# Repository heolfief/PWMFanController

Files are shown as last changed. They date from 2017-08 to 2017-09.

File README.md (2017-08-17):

# PWMFanController
This is a simple AVR based PWM PC fan controller.

The MCU is an ATtiny85.

Software in interrupt-driven. A potentiometer value is read by the ADC and then used to set the duty-cycle of a 8bits PWM, driving the fan's speed.

The board is small (33x15mm) and is designed to be directly attached to a standard potentiometer.

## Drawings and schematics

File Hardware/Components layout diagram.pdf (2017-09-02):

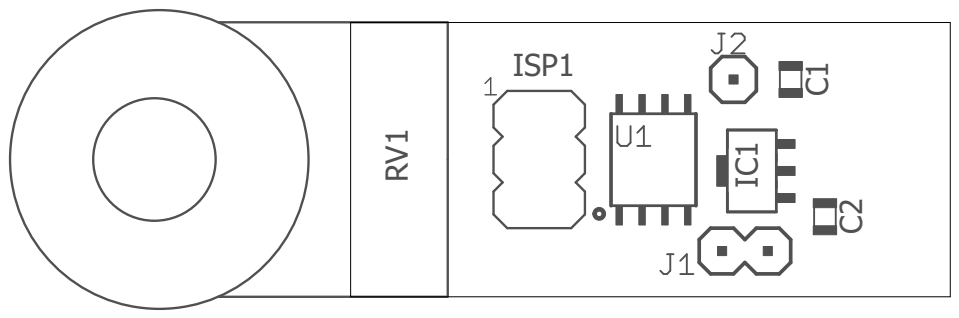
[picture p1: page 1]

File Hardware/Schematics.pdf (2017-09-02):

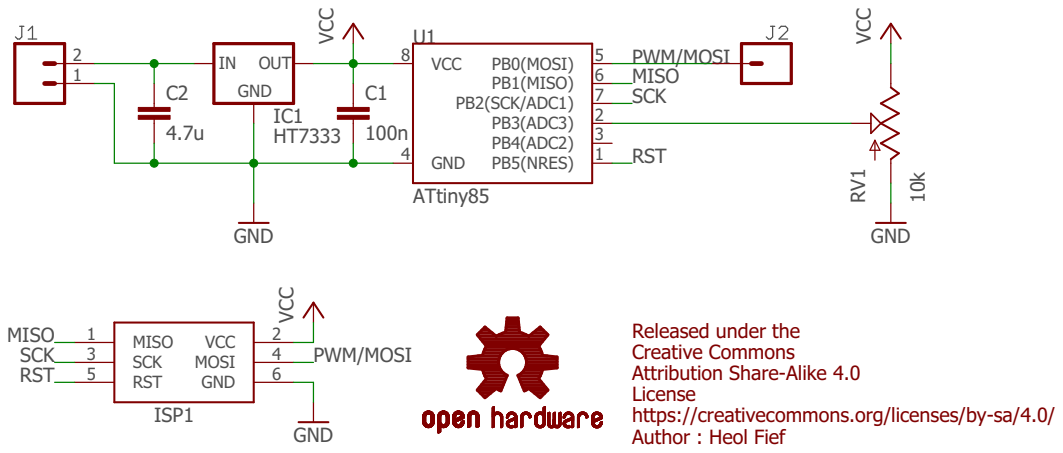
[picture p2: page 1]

Released under the
Creative Commons
Attribution Share-Alike 4.0
License
https://creativecommons.org/licenses/by-sa/4.0/
Author : Heol Fief

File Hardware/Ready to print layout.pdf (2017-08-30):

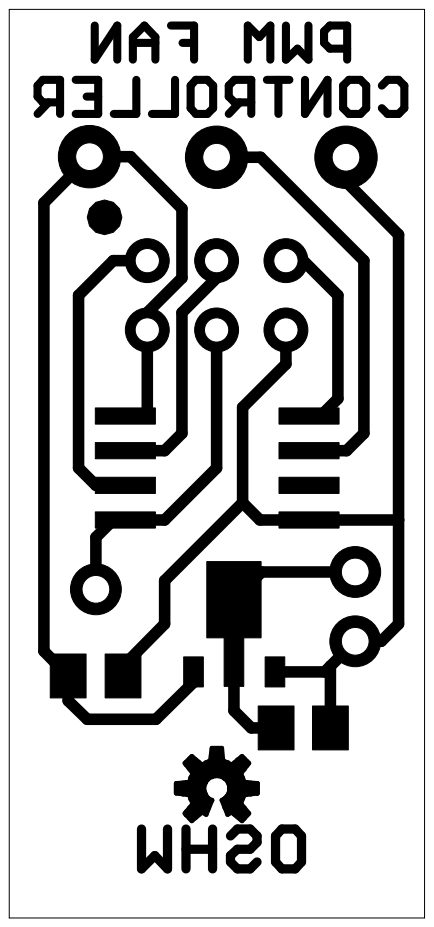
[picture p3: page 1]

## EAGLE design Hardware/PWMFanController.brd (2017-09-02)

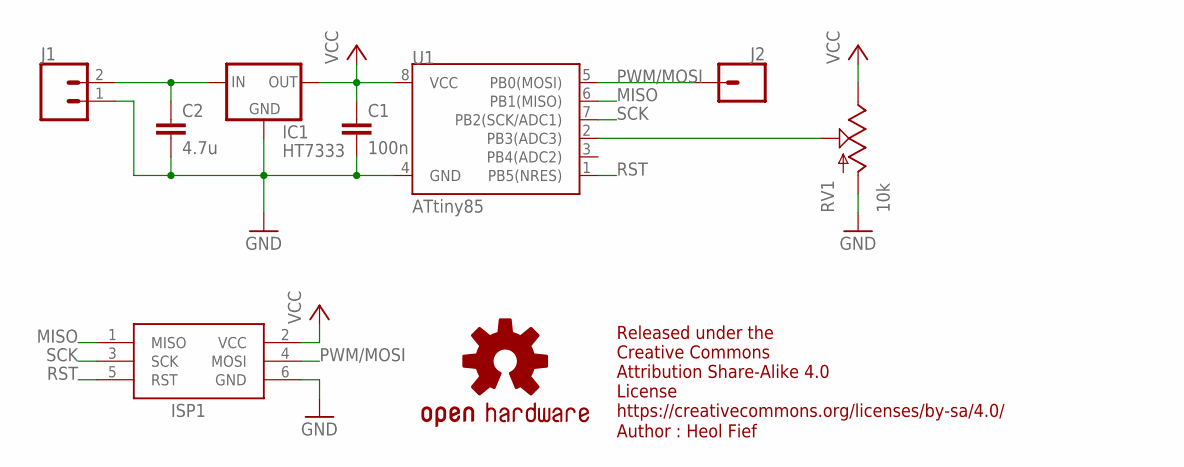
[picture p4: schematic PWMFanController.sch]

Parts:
C1: 100n; C0805K
C2: 4.7u; C0805K
IC1: HT7333; SOT-89
ISP1: AVRISP-6; AVRISP
J1: CONN_02; 1X02
J2: CONN_01; 1X01
LOGO1: OSHW-LOGOS-COPPER; OSHW-LOGO-S_COPPER
RV1: 10k; POT_MAMMOTH
U1: ATtiny85; SO08-EIAJ_MCU

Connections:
GND: C1.2, C2.2, IC1.2 (GND), ISP1.6 (GND), J1.1, RV1.P$1 (A), U1.4 (GND)
MISO: ISP1.1 (MISO), U1.6 (PB1(MISO))
unnamed: C2.1, IC1.3 (IN), IC1.4 (IN), J1.2
unnamed: RV1.P$2 (S), U1.2 (PB3(ADC3))
PWM/MOSI: ISP1.4 (MOSI), J2.1, U1.5 (PB0(MOSI))
RST: ISP1.5 (RST), U1.1 (PB5(NRES))
SCK: ISP1.3 (SCK), U1.7 (PB2(SCK/ADC1))
VCC: C1.1, IC1.1 (OUT), ISP1.2 (VCC), RV1.P$3 (E), U1.8 (VCC)

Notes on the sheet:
Released under the Creative Commons Attribution Share-Alike 4.0 License https://creativecommons.org/licenses/by-sa/4.0/
Author : Heol Fief

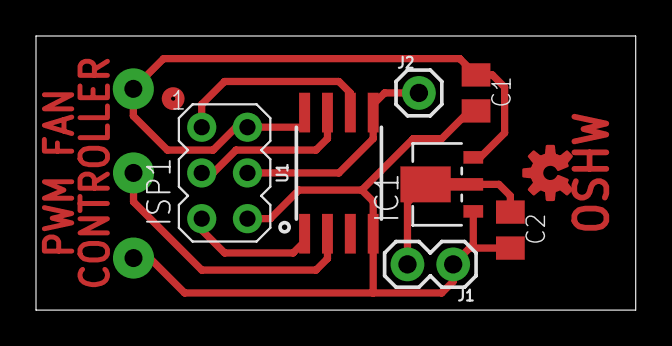
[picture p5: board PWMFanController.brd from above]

Board: 2 copper layers, 33.3 x 15.2 mm, 9 parts (0 on the bottom side), 8 nets.

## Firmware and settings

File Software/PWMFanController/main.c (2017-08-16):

/*
 * PWMFanController.c
 *
 * Created: 11/06/2017 14:01:29
 * Author : Heol FIEF
 */ 

#include <avr/io.h>
#include <avr/interrupt.h>

void init_PWM();
void init_ADC();

int main(void)
{
	init_PWM();											// Initialize non inverting Fast PWM mode on OC0A
	init_ADC();											// Initialize ADC on ADC3
	
	sei();												// Enable global interrupts
    while (1);											// PWM is driven by ADC interrupt
}

ISR(ADC_vect)											// Interrupt on ADC conversion complete
{
	OCR0A = ~ADCH;										// Set PWM duty cycle to 8 bits ADC value
	ADCSRA |= (1<<ADSC);								// Start another ADC conversion
}

void init_PWM()
{
	DDRB   |= (1<<PB0);									// PB0 as output
	
	TCCR0A |= (1<<WGM01) | (1<<WGM00);					// ... Fast PWM mode
		
	TCCR0A |= (1<<COM0A1);								// ...
	TCCR0A &= ~(1<<COM0A0);								// ... Non-inverting mode
	
	TCCR0B &= ~((1<<CS02) | (1<<CS01));					// ...
	TCCR0B |= (1<<CS00);								// ... No prescaler
}

void init_ADC()
{
	ADMUX &= ~((0<<REFS1) | (1<<REFS0));				// VCC used as Voltage Reference
	ADMUX |= (1<<ADLAR);								// ADC Left Adjust Result
	ADMUX &= ~((1<<MUX3) | (1<<MUX2));					// ...
	ADMUX |= (1<<MUX1) | (1<<MUX0);						// ... Select ADC3
	ADCSRA |= (1<<ADPS2) | (1<<ADPS1) | (1<<ADPS0);	    // ADC clock prescaler /128
	ADCSRA |= (1<<ADIE) | (1<<ADEN);					// Enable ADC and enable interrupt
	ADCSRA |= (1<<ADSC);								// Start ADC conversion
}

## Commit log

2017-08-17 Add Eagle files
    [PWMFanController.brd, PWMFanController.sch]
2017-08-30 Add layout
    Add ready to print PDF layout for toner tranfer
2017-09-02 Add author mention
    [PWMFanController.brd, PWMFanController.sch]

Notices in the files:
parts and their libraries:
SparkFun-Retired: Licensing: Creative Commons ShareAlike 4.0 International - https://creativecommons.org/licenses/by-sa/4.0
